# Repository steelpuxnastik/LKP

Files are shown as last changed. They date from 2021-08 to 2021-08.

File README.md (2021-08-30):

lkp-logo

# LKP

レンくんピアノ (Len-kun Piano)

Capacitive touch slider controller for rhythm games.

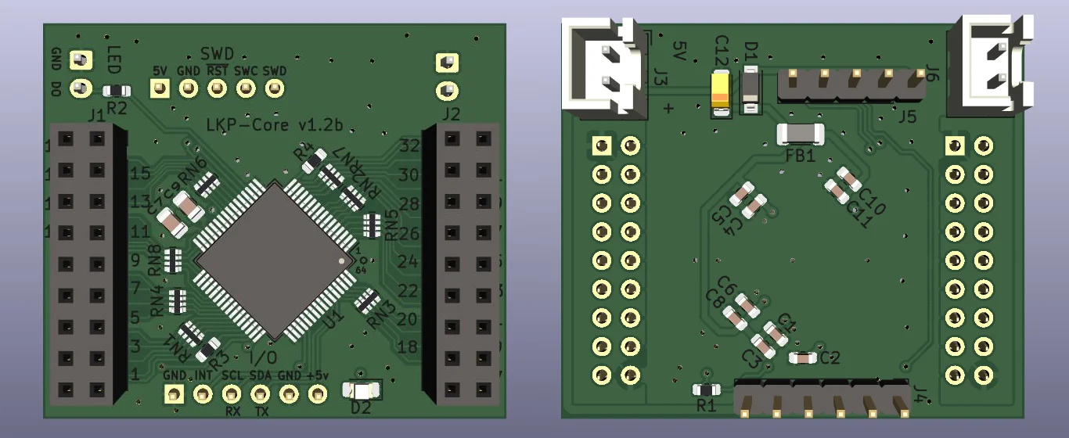
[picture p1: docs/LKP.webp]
LKP


# Contents

## pcb/LKP-Core

Microcontroller board for use with LKP electrode boards. Supports up to 32 channel of self capacitance input. Includes a WS281x LED driver channel with protection resistor. Supports I2C or UART as communication methods.

For sample firmware for use with LKP-Core, see [LKP-FW](https://github.com/Project-Alpaca/LKP-FW).

Requires KiCad version 5.99 (nightly) (supports `kicad_pcb format >= 20210816`).

### Pin mapping

I/O port:

| \#  | Description |
| --- | --- |
|  1  | GND |
|  2  | INT |
|  3  | SCL/RX |
|  4  | SDA/TX |
|  5  | GND |
|  6  | +5V |

WS281x LED connector:

| \#  | Description |
| --- | --- |
|  1  | GND |
|  2  | LED |

SWD connector:

| \#  | Description |
| --- | --- |
|  1  | VTARG |
|  2  | GND |
|  3  | RESET |
|  4  | SWCLK |
|  5  | SWDIO |

## pcb/LKP-Diva-Electrode-Tile

Electrode board for Project DIVA Future Tone slider controller. Works as a 2-tile setup. Both tiles use the same design, with right tile being a 180 degree rotated version of the left tile.

Requires KiCad version 5.99 (nightly) (supports `kicad_pcb format >= 20210228`) for hatched fills.

# BOM

## LKP-Core

- **C1, C4, C6, C10**: Generic 1uF 0603 X5R ceramic capacitor. (I used `CC0603KRX5R8BB105`)
- **C2, C3, C5, C8, C11**: Generic 100nF 0603 ceramic capacitor. (I used `CL10B104KA8NNNC`)
- **C7**: `GRM2195C1H103JA01D`.
- **C9**: `GRM21B5C2J222FWAAL`.
- **C12**: Generic 10uF EIA-3216-18 tantalum capacitor.
- **D1**: Generic SOD-123 Schottky diode (`MBR0520L`).
- **D2**: Generic 0805 LED (yellow color).
- **FB1**: Generic 1206 ferrite bead (330ohm@100MHz).
- **J1, J2**: Straight female .1" header 2x9.
- **J3**: JST XH 2 positions.
- **J4**: Straight male .1" header 1x6.
- **J5**: Straight male .1" header 1x5.
- **J6**: **Angled** male .1" header 1x2 or JST XH 2 positions
- **R1**: Generic 1kohm 5% 0603 resistor.
- **R2**: Generic 470ohm 5% 0603 resistor.
- **R3, R4**: Generic 560ohm 5% 0603 resistor.
- **RN\***: Generic 560ohm 5% 0402x4 convex resistor array (I used `4D02WGJ0561TCE`).
- **U1**: `CY8C4246AZI-M445` (or `CY8C4247AZI-M485`, Needs minor firmware modifications).

## LKP-Diva-Electrode-Tile

- **J1**: Straight male .1" SMD header 2x9 (**without** bumps at the bottom).
  - This can be hard to find. For small scale DIY manufacturing try searching "pin header double smd" on aliexpress.

# Powering

By default LKP expects 5V power. Using lower supply voltage down to 1.8V is possible by modifying the power specs in LKP-FW and adding a level shifter module to the WS281x driver pin (labeled as LED on board). Reference voltage for I/O can be approximated by tapping into the VTARG pin on the SWD port.

# Known issues / Erratas

- (LKP-Core v1.0) The reverse voltage protection diode (D1) does not protect C12. Proceed with caution when connecting the power to make sure the polarity is correct.
- (LKP-Core v1.1) When used with LKP-Assy, connector J4, J5 and J6 may collide with the bottom of LKP-Assy. A workaround would be soldering all the specified connectors on the back side of the PCB instead. Also, when using LKP-IF-Qwiic, J4 and J5 must be soldered on the back side.
- (LKP-Core v1.2b) Changes of some parts that I have and I want to use: J1, J2 to JST XH, J4 from 4 to 6 pin, C9 to 0805 size, FB1 to 1206 size and changes in silkscreen. 

[qwiic]: https://www.sparkfun.com/qwiic
[stemmaqt]: https://learn.adafruit.com/introducing-adafruit-stemma-qt/what-is-stemma-qt

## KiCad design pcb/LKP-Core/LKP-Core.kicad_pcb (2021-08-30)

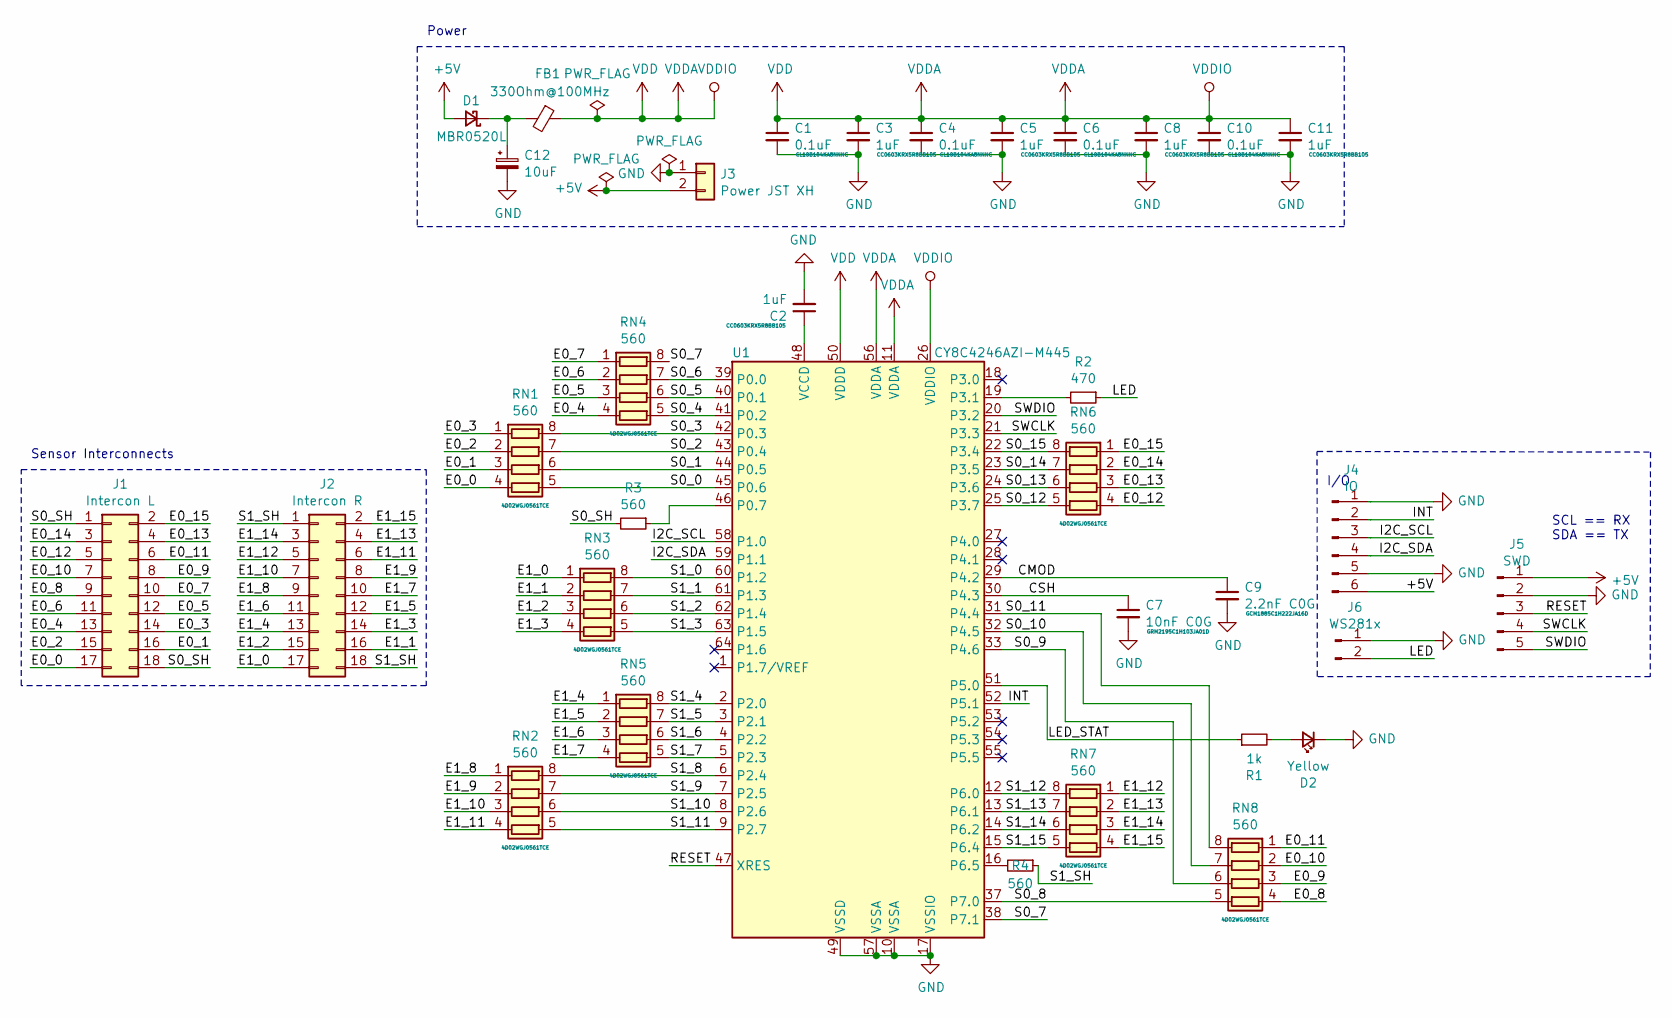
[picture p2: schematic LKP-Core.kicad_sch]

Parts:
C1, C4, C6, C10: 0.1uF; C_0603_1608Metric; Part Number CL10B104KA8NNNC
C2, C3, C5, C8, C11: 1uF; C_0603_1608Metric; Part Number CC0603KRX5R8BB105
C7: 10nF C0G; C_0805_2012Metric; Part Number GRM2195C1H103JA01D
C9: 2.2nF C0G; C_0805_2012Metric; Part Number GCM1885C1H222JA16D
C12: 10uF; CP_EIA-3216-18_Kemet-A
D1: MBR0520L; D_SOD-123; Part Number MBR0520L
D2: Yellow; LED_0805_2012Metric_Castellated
FB1: 330Ohm@100MHz; L_1206_3216Metric
J1: Intercon L; PinSocket_2x09_P2.54mm_Vertical
J2: Intercon R; PinSocket_2x09_P2.54mm_Vertical
J3: Power JST XH; JST_XH_B2B-XH-A_1x02_P2.50mm_Vertical
J4: IO; PinHeader_1x06_P2.54mm_Vertical
J5: SWD; PinHeader_1x05_P2.54mm_Vertical
J6: WS281x; JST_XH_B2B-XH-A_1x02_P2.50mm_Vertical
R1: 1k; R_0603_1608Metric
R2: 470; R_0603_1608Metric
R3, R4: 560; R_0603_1608Metric
RN1, RN2, RN3, RN4, RN5, RN6, RN7, RN8: 560; R_Array_Convex_4x0402; Part Number 4D02WGJ0561TCE
U1: CY8C4246AZI-M445; TQFP-64_10x10mm_P0.5mm; Part Number CY8C4246AZI-M445

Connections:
+5V: D1.2 (A), J3.2, J4.6, J5.1
/CMOD: C9.1, U1.29 (P4.2)
/CSH: C7.1, U1.30 (P4.3)
/E0_0: J1.17, RN1.4 (R4.1)
/E0_1: J1.16, RN1.3 (R3.1)
/E0_2: J1.15, RN1.2 (R2.1)
/E0_3: J1.14, RN1.1 (R1.1)
/E0_4: J1.13, RN4.4 (R4.1)
/E0_5: J1.12, RN4.3 (R3.1)
/E0_6: J1.11, RN4.2 (R2.1)
/E0_7: J1.10, RN4.1 (R1.1)
/E0_8: J1.9, RN8.4 (R4.1)
/E0_9: J1.8, RN8.3 (R3.1)
/E0_10: J1.7, RN8.2 (R2.1)
/E0_11: J1.6, RN8.1 (R1.1)
/E0_12: J1.5, RN6.4 (R4.1)
/E0_13: J1.4, RN6.3 (R3.1)
/E0_14: J1.3, RN6.2 (R2.1)
/E0_15: J1.2, RN6.1 (R1.1)
/E1_0: J2.17, RN3.1 (R1.1)
/E1_1: J2.16, RN3.2 (R2.1)
/E1_2: J2.15, RN3.3 (R3.1)
/E1_3: J2.14, RN3.4 (R4.1)
/E1_4: J2.13, RN5.1 (R1.1)
/E1_5: J2.12, RN5.2 (R2.1)
/E1_6: J2.11, RN5.3 (R3.1)
/E1_7: J2.10, RN5.4 (R4.1)
/E1_8: J2.9, RN2.1 (R1.1)
/E1_9: J2.8, RN2.2 (R2.1)
/E1_10: J2.7, RN2.3 (R3.1)
/E1_11: J2.6, RN2.4 (R4.1)
/E1_12: J2.5, RN7.1 (R1.1)
/E1_13: J2.4, RN7.2 (R2.1)
/E1_14: J2.3, RN7.3 (R3.1)
/E1_15: J2.2, RN7.4 (R4.1)
/I2C_SCL: J4.3, U1.58 (P1.0)
/I2C_SDA: J4.4, U1.59 (P1.1)
/INT: J4.2, U1.52 (P5.1)
/LED: J6.2, R2.1
/LED_STAT: R1.1, U1.51 (P5.0)
/RESET: J5.3, U1.47 (XRES)
/S0_0: RN1.5 (R4.2), U1.45 (P0.6)
/S0_1: RN1.6 (R3.2), U1.44 (P0.5)
/S0_2: RN1.7 (R2.2), U1.43 (P0.4)
/S0_3: RN1.8 (R1.2), U1.42 (P0.3)
/S0_4: RN4.5 (R4.2), U1.41 (P0.2)
/S0_5: RN4.6 (R3.2), U1.40 (P0.1)
/S0_6: RN4.7 (R2.2), U1.39 (P0.0)
/S0_7: RN4.8 (R1.2), U1.38 (P7.1)
/S0_8: RN8.5 (R4.2), U1.37 (P7.0)
/S0_9: RN8.6 (R3.2), U1.33 (P4.6)
/S0_10: RN8.7 (R2.2), U1.32 (P4.5)
/S0_11: RN8.8 (R1.2), U1.31 (P4.4)
/S0_12: RN6.5 (R4.2), U1.25 (P3.7)
/S0_13: RN6.6 (R3.2), U1.24 (P3.6)
/S0_14: RN6.7 (R2.2), U1.23 (P3.5)
/S0_15: RN6.8 (R1.2), U1.22 (P3.4)
/S0_SH: J1.1, J1.18, R3.2
/S1_0: RN3.8 (R1.2), U1.60 (P1.2)
/S1_1: RN3.7 (R2.2), U1.61 (P1.3)
/S1_2: RN3.6 (R3.2), U1.62 (P1.4)
/S1_3: RN3.5 (R4.2), U1.63 (P1.5)
/S1_4: RN5.8 (R1.2), U1.2 (P2.0)
/S1_5: RN5.7 (R2.2), U1.3 (P2.1)
/S1_6: RN5.6 (R3.2), U1.4 (P2.2)
/S1_7: RN5.5 (R4.2), U1.5 (P2.3)
/S1_8: RN2.8 (R1.2), U1.6 (P2.4)
/S1_9: RN2.7 (R2.2), U1.7 (P2.5)
/S1_10: RN2.6 (R3.2), U1.8 (P2.6)
/S1_11: RN2.5 (R4.2), U1.9 (P2.7)
/S1_12: RN7.8 (R1.2), U1.12 (P6.0)
/S1_13: RN7.7 (R2.2), U1.13 (P6.1)
/S1_14: RN7.6 (R3.2), U1.14 (P6.2)
/S1_15: RN7.5 (R4.2), U1.15 (P6.4)
/S1_SH: J2.1, J2.18, R4.1
/SWCLK: J5.4, U1.21 (P3.3)
/SWDIO: J5.5, U1.20 (P3.2)
GND: C1.2, C2.2, C3.2, C4.2, C5.2, C6.2, C7.2, C8.2, C9.2, C10.2, C11.2, C12.2, D2.1 (K), J3.1, J4.1, J4.5, J5.2, J6.1, U1.10 (VSSA), U1.17 (VSSIO), U1.49 (VSSD), U1.57 (VSSA)
unnamed: C2.1, U1.48 (VCCD)
unnamed: C12.1, D1.1 (K), FB1.2
unnamed: D2.2 (A), R1.2
unnamed: R2.2, U1.19 (P3.1)
unnamed: R3.1, U1.46 (P0.7)
unnamed: R4.2, U1.16 (P6.5)
VDD: C1.1, C3.1, C4.1, C5.1, C6.1, C8.1, C10.1, C11.1, FB1.1, U1.11 (VDDA), U1.26 (VDDIO), U1.50 (VDDD), U1.56 (VDDA)

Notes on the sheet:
Sensor Interconnects
Power
I/O
SCL == RX SDA == TX

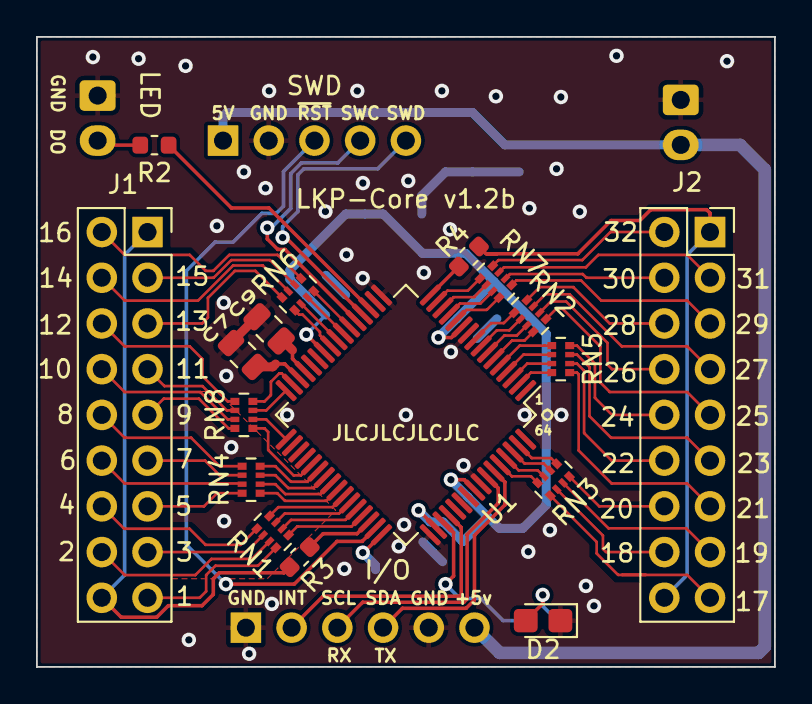
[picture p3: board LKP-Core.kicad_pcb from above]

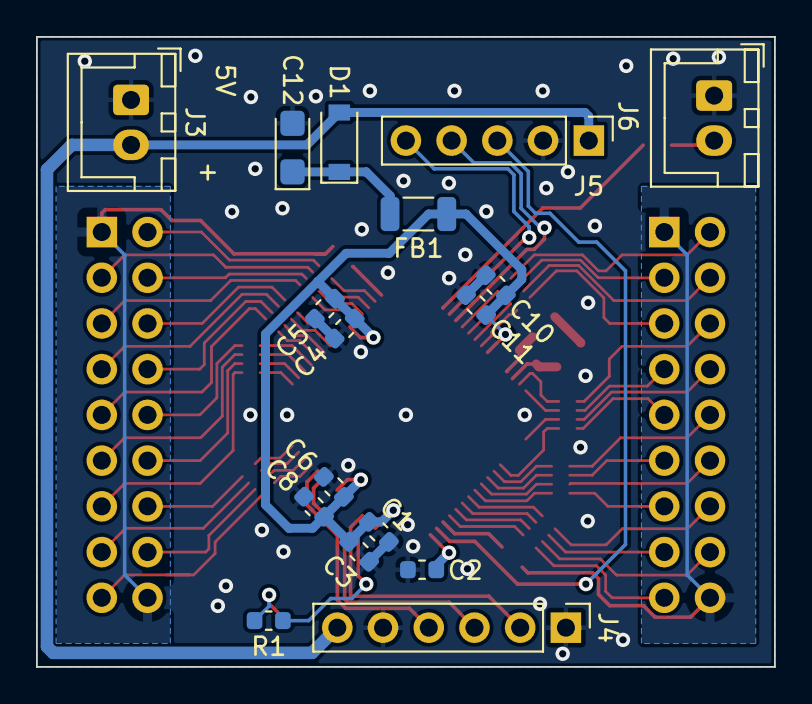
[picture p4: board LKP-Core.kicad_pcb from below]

Board: 2 copper layers, 41.0 x 35.0 mm, 34 parts (17 on the bottom side), 85 nets.

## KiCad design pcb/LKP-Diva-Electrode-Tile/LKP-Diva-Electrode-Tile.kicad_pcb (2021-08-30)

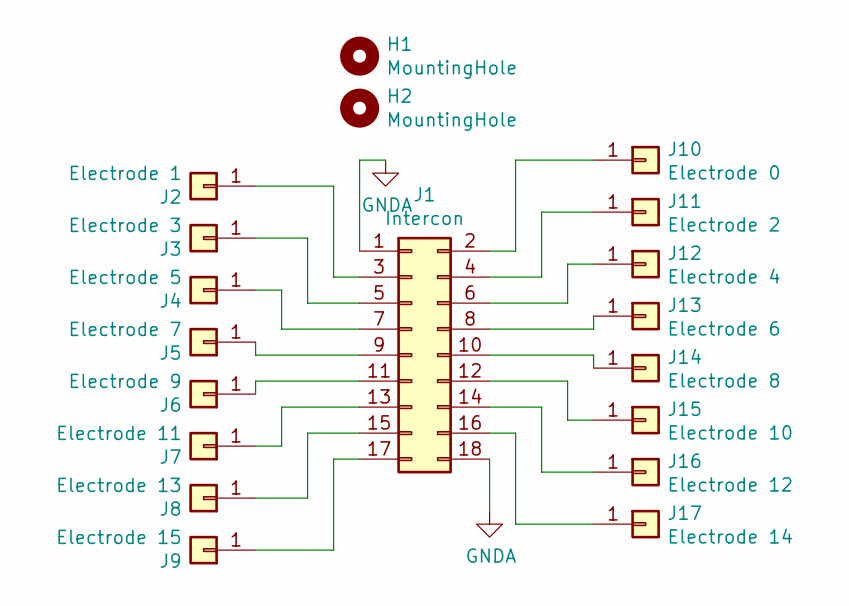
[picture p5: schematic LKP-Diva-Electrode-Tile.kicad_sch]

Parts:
H1, H2: MountingHole; MountingHole_3.2mm_M3_ISO7380
J1: Intercon; PinHeader_2x09_P2.54mm_Vertical_SMD
J2: Electrode 1; CapSense_Electrode_14.6x39mm
J3: Electrode 3; CapSense_Electrode_14.6x39mm
J4: Electrode 5; CapSense_Electrode_14.6x39mm
J5: Electrode 7; CapSense_Electrode_14.6x39mm
J6: Electrode 9; CapSense_Electrode_14.6x39mm
J7: Electrode 11; CapSense_Electrode_14.6x39mm
J8: Electrode 13; CapSense_Electrode_14.6x39mm
J9: Electrode 15; CapSense_Electrode_14.6x39mm
J10: Electrode 0; CapSense_Electrode_14.6x39mm
J11: Electrode 2; CapSense_Electrode_14.6x39mm
J12: Electrode 4; CapSense_Electrode_14.6x39mm
J13: Electrode 6; CapSense_Electrode_14.6x39mm
J14: Electrode 8; CapSense_Electrode_14.6x39mm
J15: Electrode 10; CapSense_Electrode_14.6x39mm
J16: Electrode 12; CapSense_Electrode_14.6x39mm
J17: Electrode 14; CapSense_Electrode_14.6x39mm

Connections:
GNDA: J1.1, J1.18
unnamed: J1.2, J10.1
unnamed: J1.3, J2.1
unnamed: J1.4, J11.1
unnamed: J1.5, J3.1
unnamed: J1.6, J12.1
unnamed: J1.7, J4.1
unnamed: J1.8, J13.1
unnamed: J1.9, J5.1
unnamed: J1.10, J14.1
unnamed: J1.11, J6.1
unnamed: J1.12, J15.1
unnamed: J1.13, J7.1
unnamed: J1.14, J16.1
unnamed: J1.15, J8.1
unnamed: J1.16, J17.1
unnamed: J1.17, J9.1

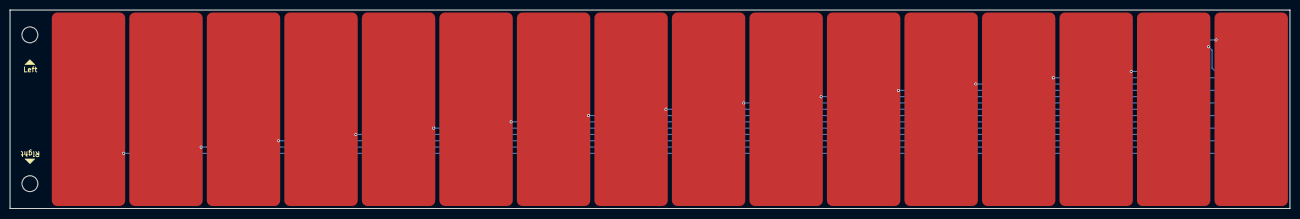
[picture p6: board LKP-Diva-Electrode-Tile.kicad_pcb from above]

Board: 2 copper layers, 258.0 x 40.0 mm, 19 parts (1 on the bottom side), 17 nets.
